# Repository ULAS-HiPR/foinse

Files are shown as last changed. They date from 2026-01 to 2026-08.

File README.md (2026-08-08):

# Foinse

Foinse is the power-source and monitoring node in [Ogma](https://sean-osullivan.com/projects/ogma/), the University of Limerick Aeronautics Society's modular avionics stack for high-powered rocketry.

## Role

- Generates and distributes the shared stack power rails.
- Measures battery and servo current.
- Reports power health over the 500 kbit/s CAN bus.
- Provides the stack's electrical entry point while each node performs its own local regulation.

## Repository

- `hardware/` - KiCad design and manufacturing outputs.
- `firmware/` - embedded firmware, power-path probes, and tests.

## Status

Rev 1 firmware and hardware bring-up continue on [`ogma/flight-hardening`](https://github.com/ULAS-HiPR/foinse/tree/ogma/flight-hardening). Release-candidate firmware builds and software tests pass, but hardware-in-the-loop validation is still underway. Foinse is not yet flight-proven.

## Manufacturing support

Rev 1 PCB fabrication was sponsored through [EasyEDA Education](https://easyeda.com/education) and manufactured by [JLCPCB](https://jlcpcb.com/). The board was designed in KiCad and imported into EasyEDA Pro for the sponsorship and manufacturing workflow.

## More information

See the [Ogma project write-up](https://sean-osullivan.com/projects/ogma/) for the complete stack, bring-up work, and current status.

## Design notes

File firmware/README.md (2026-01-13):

# Foinse

Foinse is in charge of deploying parachutes either through servo’s or ematchs

# Set-Up

```bash
git clone git@github.com:ULAS-HiPR/foinse.git
cd foinse
git submodule update --init --recursive
```

# Libraries used:

## From Braiteoiri:

- Servo
- Ematch
- LED

## From Comheadan:

- CAN
- PWM

## Other:

- FreeRTOS

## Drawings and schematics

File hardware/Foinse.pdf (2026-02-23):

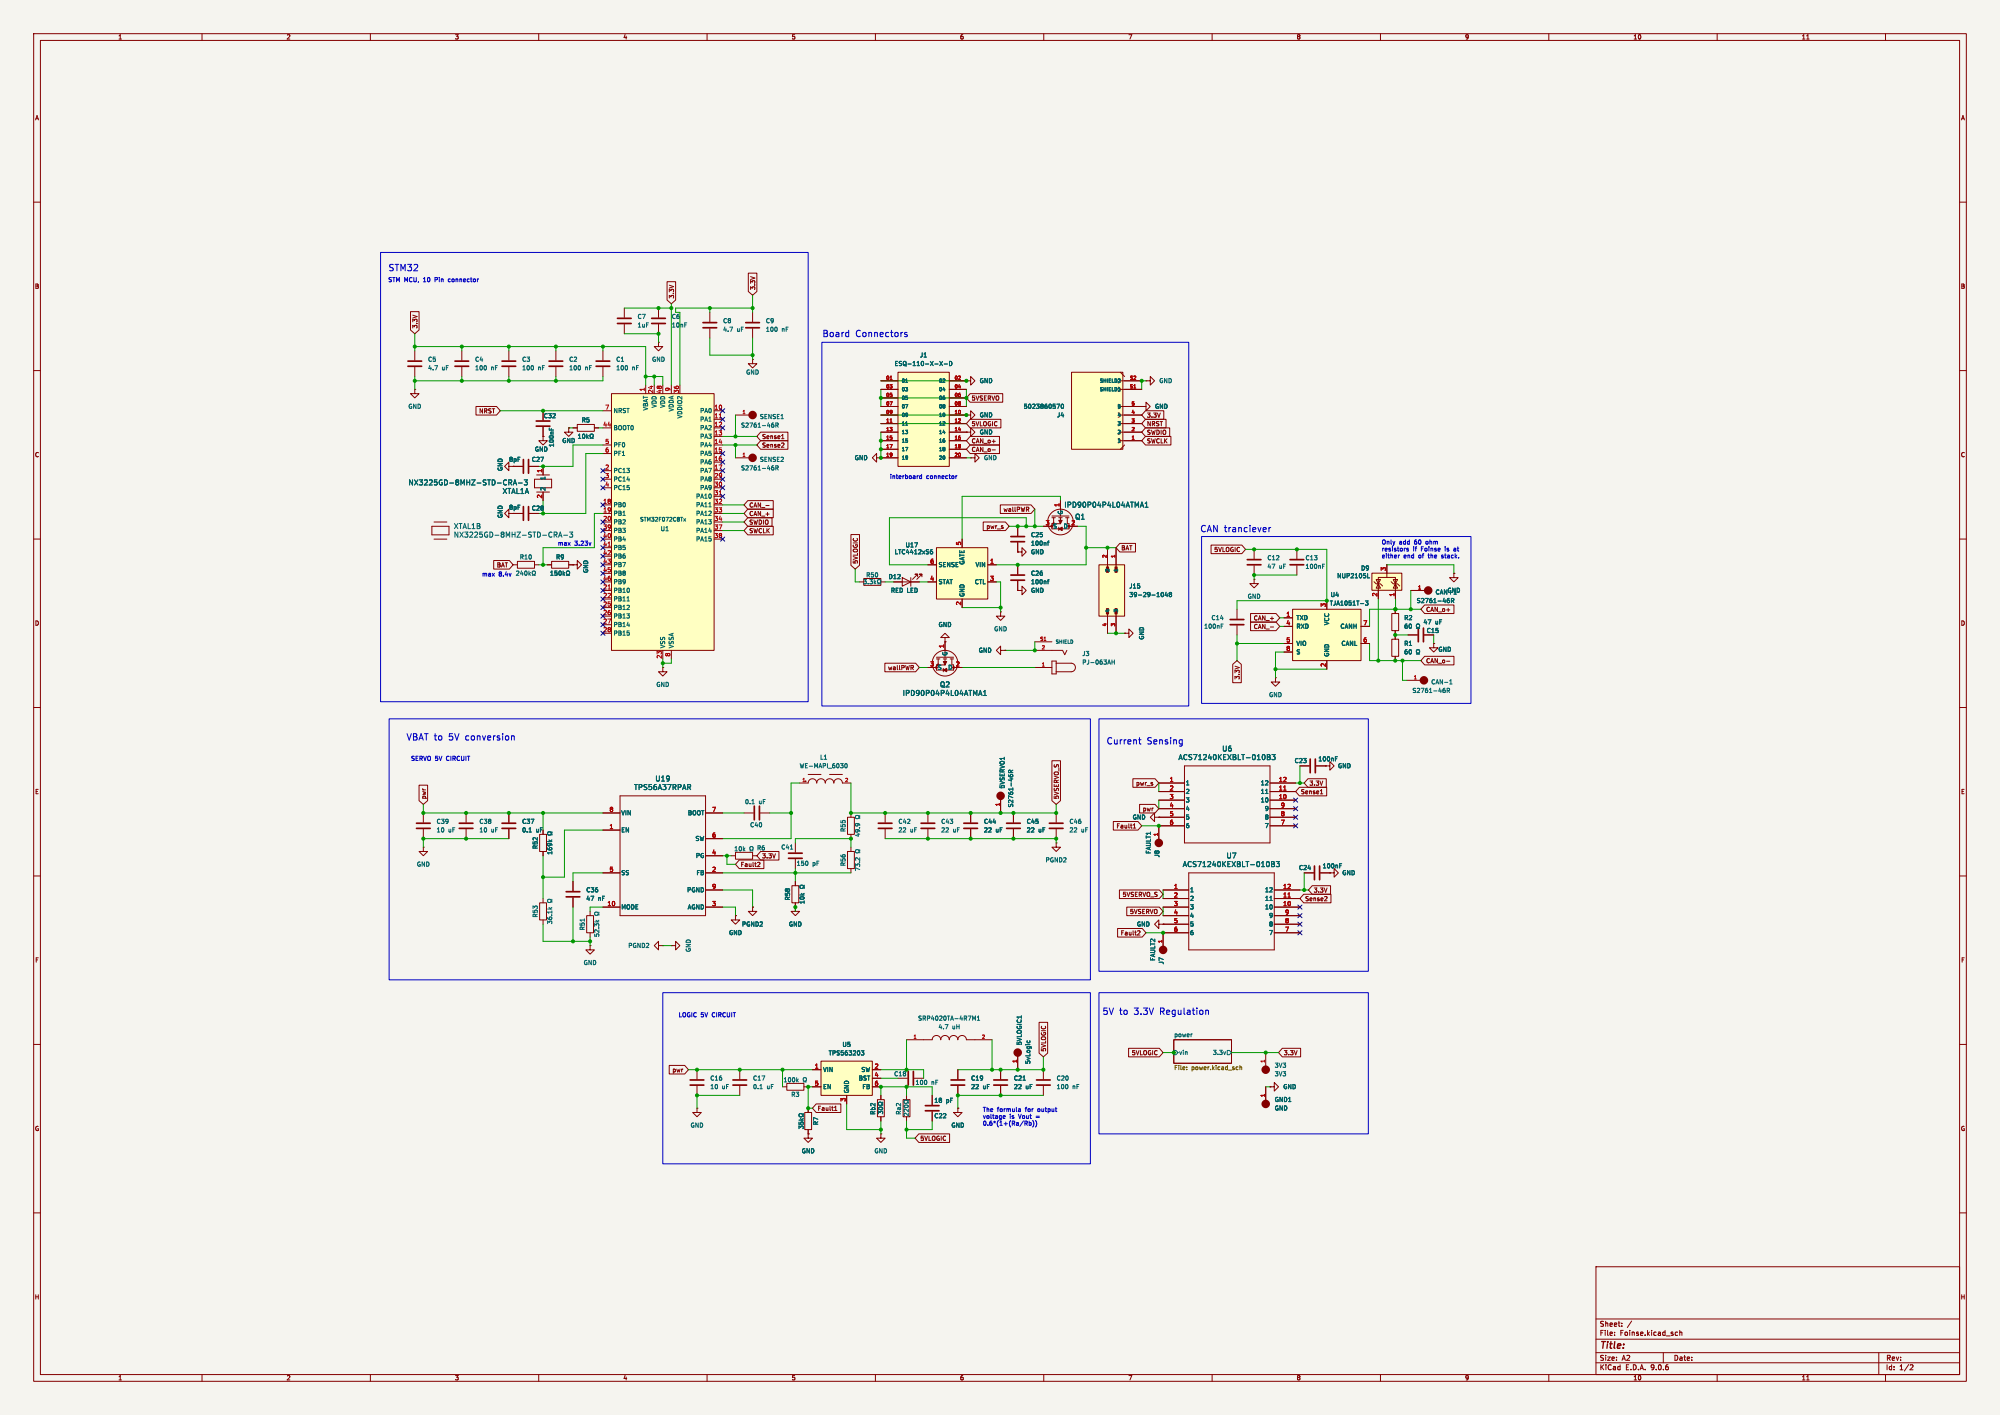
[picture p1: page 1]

1 VDD 24 VDD 48 VSS 23 VDDA

3 SW 2 BST 4 FB 6 U5 TPS563203 R52 169k þÿ©

3 SW 2 BST 4 FB 6 GND

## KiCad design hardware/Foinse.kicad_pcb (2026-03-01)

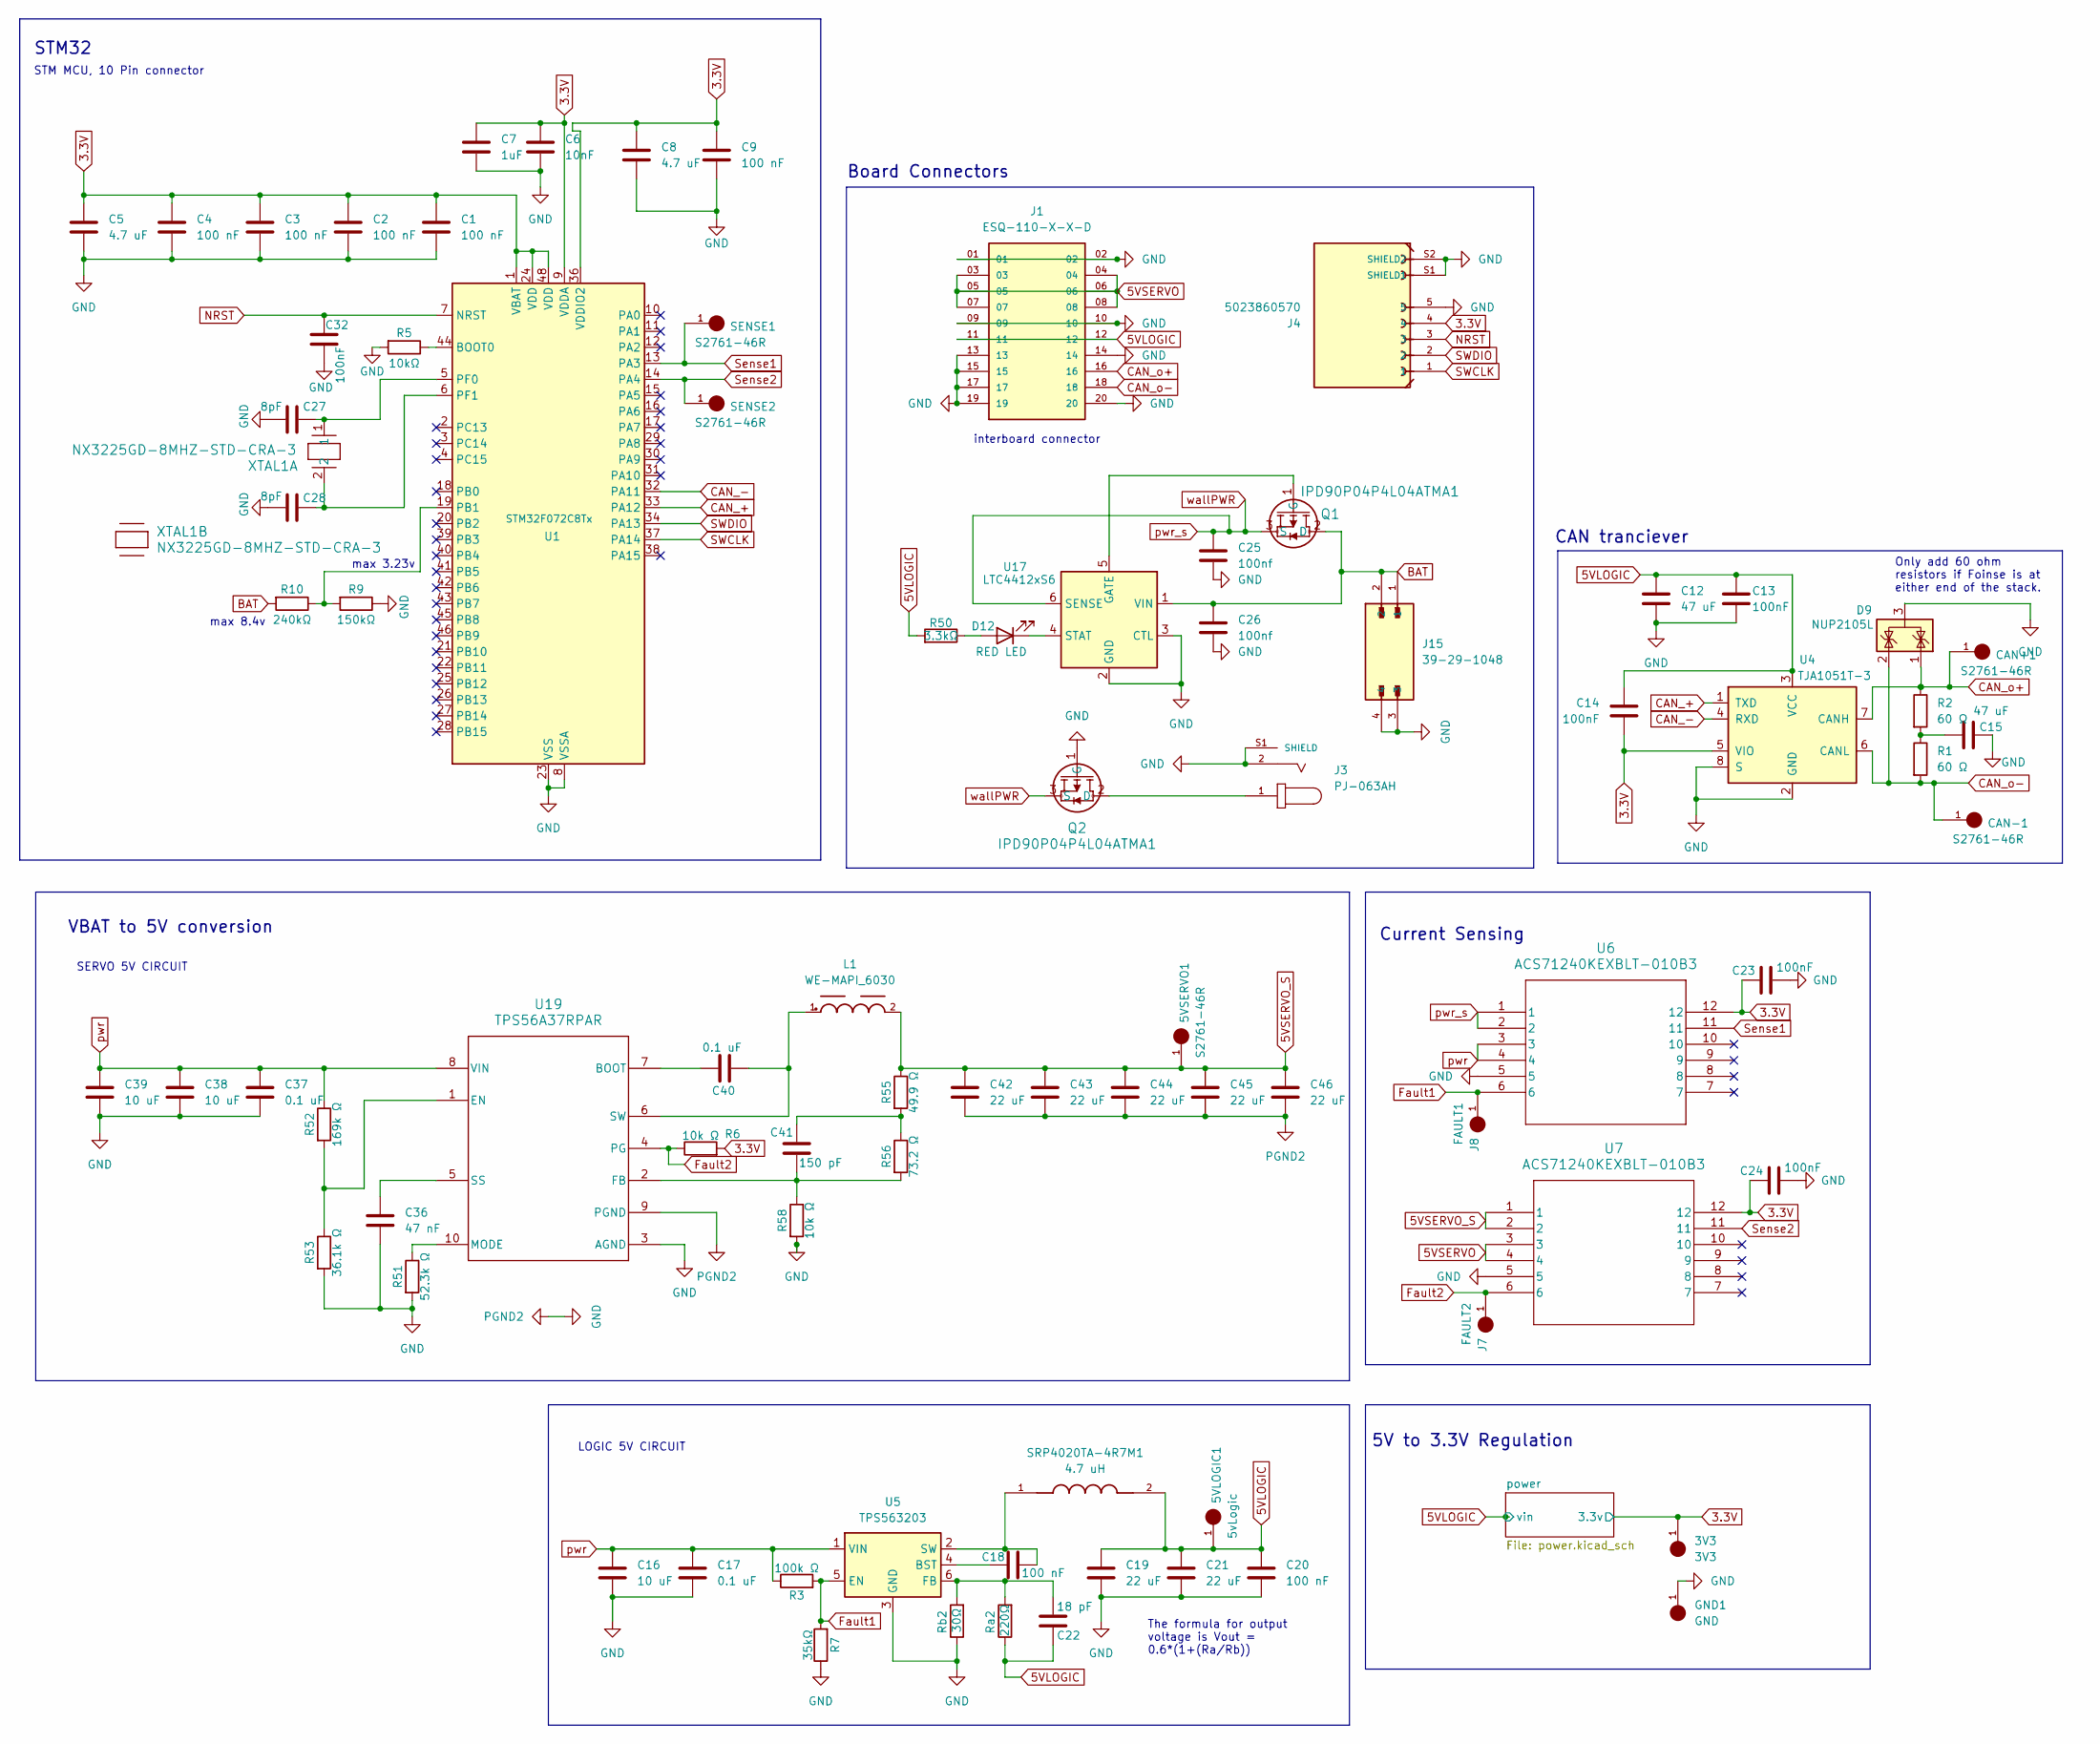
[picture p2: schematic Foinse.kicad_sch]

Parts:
3V3: 3V3; HARWIN_S2761-46R; PARTREV 1
5VLOGIC1: 5vLogic; HARWIN_S2761-46R; PARTREV 1
5VSERVO1: S2761-46R; HARWIN_S2761-46R; PARTREV 1
C1, C2, C3, C4, C9, C18, C20: 100 nF; C_0402_1005Metric
C5, C8: 4.7 uF; C_0402_1005Metric
C6: 10nF; C_0402_1005Metric
C7: 1uF; C_0402_1005Metric
C12, C15: 47 uF; C_0402_1005Metric
C13, C14, C23, C24, C32: 100nF; C_0402_1005Metric
C16, C38, C39: 10 uF; C_0402_1005Metric
C17, C37, C40: 0.1 uF; C_0402_1005Metric
C19, C21, C42, C43, C44, C45, C46: 22 uF; C_0402_1005Metric
C22: 18 pF; C_0402_1005Metric
C25, C26: 100nf; C_0402_1005Metric
C27, C28: 8pF; C_0402_1005Metric
C36: 47 nF; C_0402_1005Metric
C41: 150 pF; C_0402_1005Metric
CAN+1: S2761-46R; HARWIN_S2761-46R; PARTREV 1
CAN-1: S2761-46R; HARWIN_S2761-46R; PARTREV 1
D9: NUP2105L; SOT-23
D12: RED LED; LED_0402_1005Metric
GND1: GND; HARWIN_S2761-46R; PARTREV 1
J1: ESQ-110-X-X-D; SAMTEC_ESQ-110-14-G-D; PARTREV NA
J3: PJ-063AH; CUI_PJ-063AH; PARTREV 1.02
J4: 5023860570; MOLEX_5023860570; PARTREV F
J7: FAULT2; HARWIN_S2761-46R; PARTREV 1
J8: FAULT1; HARWIN_S2761-46R; PARTREV 1
J15: 39-29-1048; MOLEX_39-29-1048
L1: WE-MAPI_6030
Q1, Q2: IPD90P04P4L04ATMA1; PG-TO252-3-313_INF
R1, R2: 60 Ω; R_0402_1005Metric
R3: 100k Ω; R_0402_1005Metric
R5: 10kΩ; R_0402_1005Metric
R6, R58: 10k Ω; R_0402_1005Metric
R7: 35kΩ; R_0402_1005Metric
R9: 150kΩ; R_0402_1005Metric
R10: 240kΩ; R_0402_1005Metric
R50: 3.3kΩ; R_0402_1005Metric
R51: 52.3k Ω; R_0402_1005Metric
R52: 169k Ω; R_0402_1005Metric
R53: 36.1k Ω; R_0402_1005Metric
R55: 49.9 Ω; R_0402_1005Metric
R56: 73.2 Ω; R_0402_1005Metric
Ra2: 220Ω; R_0402_1005Metric
Rb2: 30Ω; R_0402_1005Metric
SENSE1, SENSE2: S2761-46R; HARWIN_S2761-46R; PARTREV 1
SRP4020TA-4R7M1: 4.7 uH; IND_SRP4020TA-4R7M
U1: STM32F072C8Tx; LQFP-48_7x7mm_P0.5mm
U4: TJA1051T-3; SOIC-8_3.9x4.9mm_P1.27mm
U5: TPS563203; SOT-563
U6, U7: ACS71240KEXBLT-010B3; QFN12_ACS711KEXLT-31AB-T_ALM
U17: LTC4412xS6; TSOT-23-6
U19: TPS56A37RPAR; RPA0010A-MFG
XTAL1: NX3225GD-8MHZ-STD-CRA-3; XTAL_NX3225GD-8MHZ-STD-CRA-3_NDK

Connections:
3.3V: 3V3.1, C1.1, C2.1, C3.1, C4.1, C5.1, C6.1, C7.1, C8.1, C9.1, C14.1, C23.2, C24.2, J4.4, R6.2, U1.1 (VBAT), U1.9 (VDDA), U1.24 (VDD), U1.36 (VDDIO2), U1.48 (VDD), U4.5 (VIO), U6.12, U7.12; also elsewhere on the board
5VLOGIC: 5VLOGIC1.1, C12.1, C13.1, C14.2, C19.1, C20.1, C21.1, C22.2, J1.11, J1.12, R50.2, Ra2.1, SRP4020TA-4R7M1.2, U4.3 (VCC); also elsewhere on the board
5VSERVO: J1.03, J1.04, J1.05, J1.06, J1.07, J1.08, U7.3, U7.4
5VSERVO_S: 5VSERVO1.1, C42.1, C43.1, C44.1, C45.1, C46.1, L1.2, R55.1, U7.1, U7.2; also elsewhere on the board
BAT: C26.1, J15.1, J15.2, Q1.2 (D), R10.2, U17.1 (VIN)
CAN_+: U1.33 (PA12), U4.1 (TXD)
CAN_-: U1.32 (PA11), U4.4 (RXD)
CAN_o+: CAN+1.1, D9.1 (K), J1.16, R2.1, U4.7 (CANH); also elsewhere on the board
CAN_o-: CAN-1.1, D9.2 (K), J1.18, R1.2, U4.6 (CANL); also elsewhere on the board
Fault1: J8.1, R3.2, R7.2, U5.5 (EN), U6.6; also elsewhere on the board
Fault2: J7.1, R6.1, U7.6, U19.4 (PG); also elsewhere on the board
GND: C1.2, C2.2, C3.2, C4.2, C5.2, C6.2, C7.2, C8.2, C9.2, C12.2, C13.2, C15.2, C16.2, C17.2, C19.2, C20.2, C21.2, C23.1, C24.1, C25.2, C26.2, C27.1, C28.2, C32.2, C36.2, C37.2, C38.2, C39.2, C42.2, C43.2, C44.2, C45.2, C46.2, D9.3 (A), GND1.1, J1.01, J1.02, J1.09, J1.10, J1.13, J1.14, J1.15, J1.17, J1.19, J1.20, J3.2, J3.S1 (SHIELD), J3.S2 (SHIELD), J4.5, J4.S1 (SHIELD1), J4.S2 (SHIELD2), J15.3, J15.4, Q2.1 (G), R5.2, R7.1, R9.1, R51.2, R53.2, R58.2, Rb2.1, U1.8 (VSSA), U1.23 (VSS), U1.35 (VSS), U1.47 (VSS), U4.2 (GND), U4.8 (S), U5.3 (GND), U6.5, U7.5, U17.2 (GND), U17.3 (CTL), U19.3 (AGND), U19.9 (PGND); also elsewhere on the board
NRST: C32.1, J4.3, U1.7 (NRST)
unnamed: C15.1, R1.1, R2.2
unnamed: C41.1, R55.2, R56.1
unnamed: D12.2 (A), R50.1
unnamed: D12.1 (K), U17.4 (STAT)
unnamed: Q1.1 (G), U17.5 (GATE)
unnamed: J3.1, Q2.2 (D)
unnamed: R5.1, U1.44 (BOOT0)
unnamed: R9.2, R10.1, U1.19 (PB1)
unnamed: C27.2, U1.5 (PF0), XTAL1.1
unnamed: C28.1, U1.6 (PF1), XTAL1.2
unnamed: C18.2, U5.4 (BST)
unnamed: C22.1, Ra2.2, Rb2.2, U5.6 (FB)
unnamed: C18.1, SRP4020TA-4R7M1.1, U5.2 (SW)
unnamed: C40.1, U19.7 (BOOT)
unnamed: R52.2, R53.1, U19.1 (EN)
unnamed: C41.2, R56.2, R58.1, U19.2 (FB)
unnamed: R51.1, U19.10 (MODE)
unnamed: C36.1, U19.5 (SS)
unnamed: C40.2, L1.1, U19.6 (SW)
SWCLK: J4.1, U1.37 (PA14)
SWDIO: J4.2, U1.34 (PA13)
Sense1: SENSE1.1, U1.13 (PA3), U6.11; also elsewhere on the board
Sense2: SENSE2.1, U1.14 (PA4), U7.11; also elsewhere on the board
pwr: C16.1, C17.1, C37.1, C38.1, C39.1, R3.1, R52.1, U5.1 (VIN), U6.3, U6.4, U19.8 (VIN)
pwr_s: C25.1, Q1.3 (S), Q2.3 (S), U6.1, U6.2, U17.6 (SENSE)

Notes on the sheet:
max 3.23v
Board Connectors
5V to 3.3V Regulation
Current Sensing
interboard connector
STM MCU, 10 Pin connector
STM32
max 8.4v
VBAT to 5V conversion
CAN tranciever
LOGIC 5V CIRCUIT
SERVO 5V CIRCUIT
Only add 60 ohm resistors if Foinse is at either end of the stack.
The formula for output voltage is Vout = 0.6*(1+(Ra/Rb))

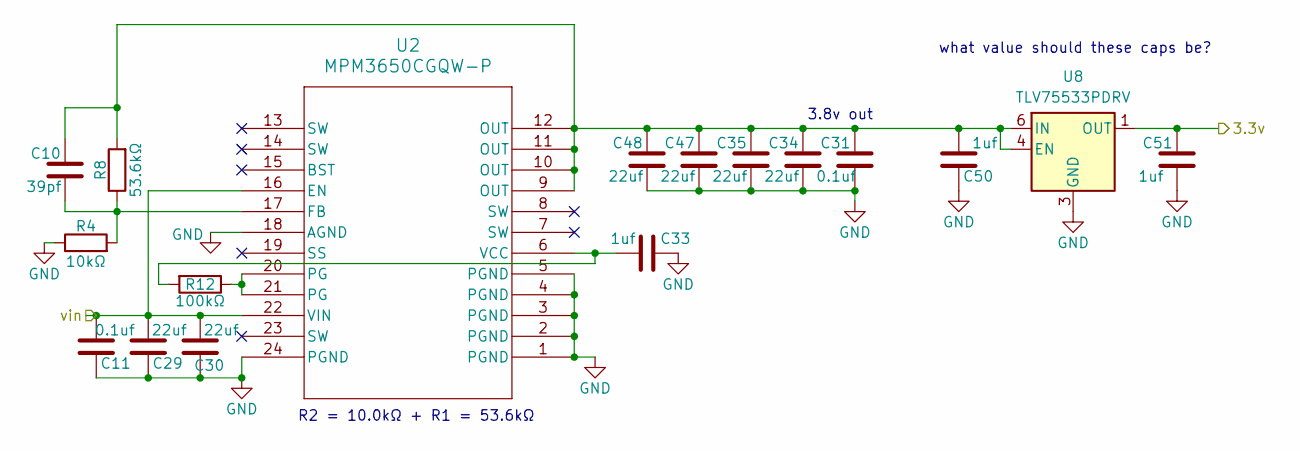
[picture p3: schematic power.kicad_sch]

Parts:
C10: 39pf; C_0402_1005Metric
C11, C31: 0.1uf; C_0402_1005Metric
C29, C30, C34, C35, C47, C48: 22uf; C_0402_1005Metric
C33, C50, C51: 1uf; C_0402_1005Metric
R4: 10kΩ; R_0402_1005Metric
R8: 53.6kΩ; R_0402_1005Metric
R12: 100kΩ; R_0402_1005Metric
U2: MPM3650CGQW-P; QFN-24_MPM3650_MNP
U8: TLV75533PDRV; WSON-6-1EP_2x2mm_P0.65mm_EP1x1.6mm

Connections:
3.3V: C51.1, U8.1 (OUT); also elsewhere on the board
5VLOGIC: C11.2, C29.2, C30.2, U2.16 (EN), U2.22 (VIN); also elsewhere on the board
GND: C11.1, C29.1, C30.1, C31.2, C33.1, C34.2, C35.2, C47.2, C48.2, C50.1, C51.2, R4.1, U2.1 (PGND), U2.2 (PGND), U2.3 (PGND), U2.4 (PGND), U2.5 (PGND), U2.18 (AGND), U2.24 (PGND), U8.3 (GND), U8.7 (GND); also elsewhere on the board
unnamed: R12.1, U2.20 (PG), U2.21 (PG)
unnamed: C10.2, R4.2, R8.1, U2.17 (FB)
unnamed: C33.2, R12.2, U2.6 (VCC)
unnamed: C10.1, C31.1, C34.1, C35.1, C47.1, C48.1, C50.2, R8.2, U2.9 (OUT), U2.10 (OUT), U2.11 (OUT), U2.12 (OUT), U8.4 (EN), U8.6 (IN)

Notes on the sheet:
R2 = 10.0kΩ + R1 = 53.6kΩ
3.8v out
what value should these caps be?

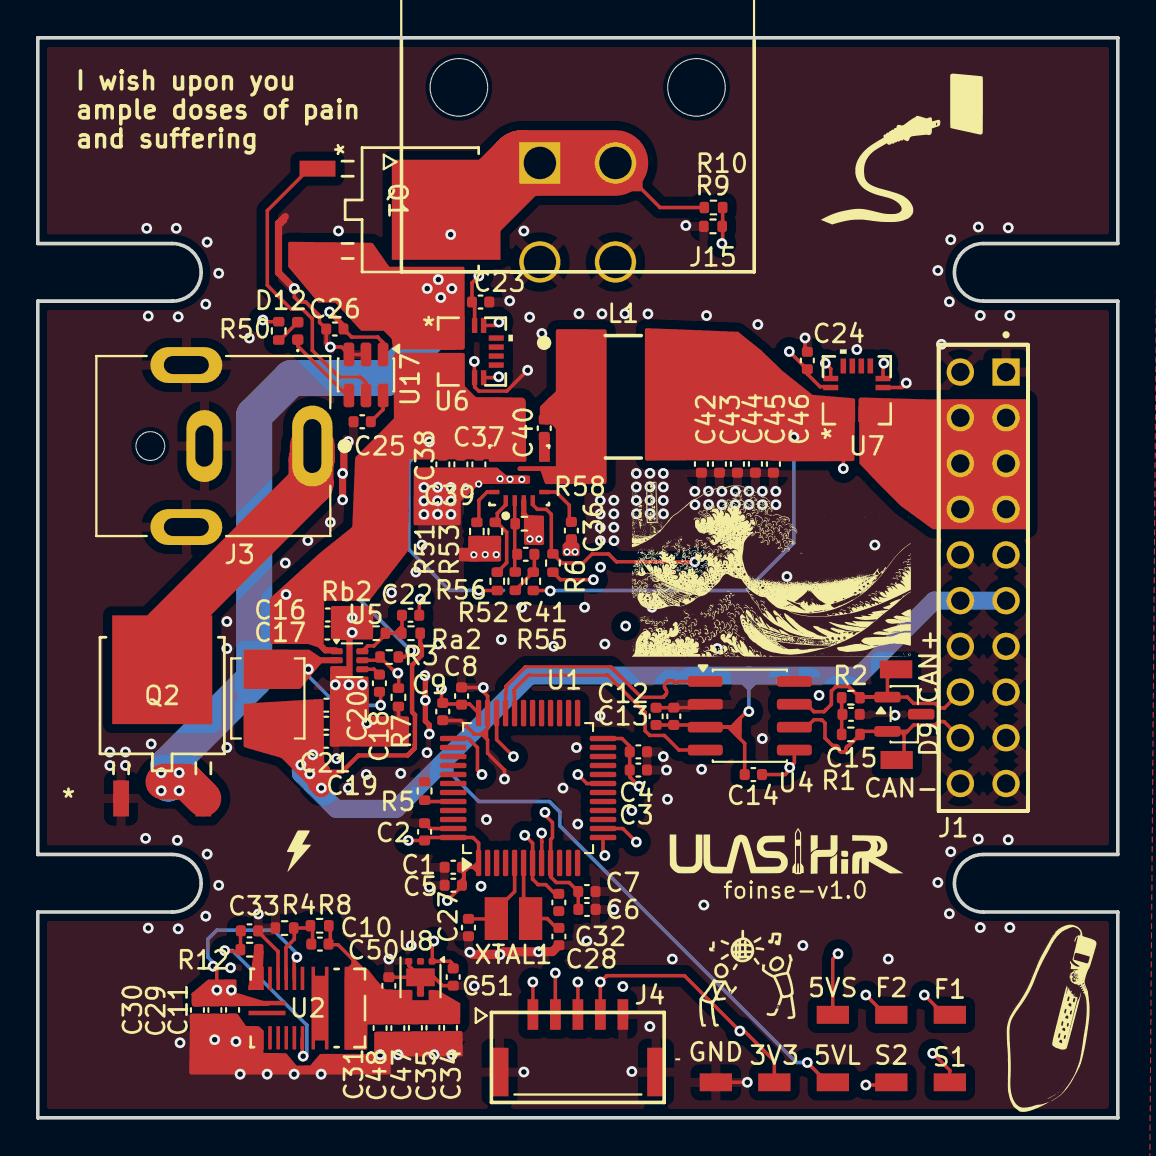
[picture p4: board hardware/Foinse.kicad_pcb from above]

Board: 6 copper layers, 60.0 x 60.0 mm, 100 parts (0 on the bottom side), 42 nets.

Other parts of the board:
5VL: 5vLogic; HARWIN_S2761-46R
5VS: S2761-46R; HARWIN_S2761-46R
CAN+: S2761-46R; HARWIN_S2761-46R
CAN-: S2761-46R; HARWIN_S2761-46R
F1: FAULT1; HARWIN_S2761-46R
F2: FAULT2; HARWIN_S2761-46R
GND: GND; HARWIN_S2761-46R
S1, S2: S2761-46R; HARWIN_S2761-46R

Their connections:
5VLOGIC: 5VL.1; also elsewhere on the board
5VSERVO_S: 5VS.1; also elsewhere on the board
CAN_o+: CAN+.1; also elsewhere on the board
CAN_o-: CAN-.1; also elsewhere on the board
Fault1: F1.1; also elsewhere on the board
Fault2: F2.1; also elsewhere on the board
GND: GND.1; also elsewhere on the board
Sense1: S1.1; also elsewhere on the board
Sense2: S2.1; also elsewhere on the board

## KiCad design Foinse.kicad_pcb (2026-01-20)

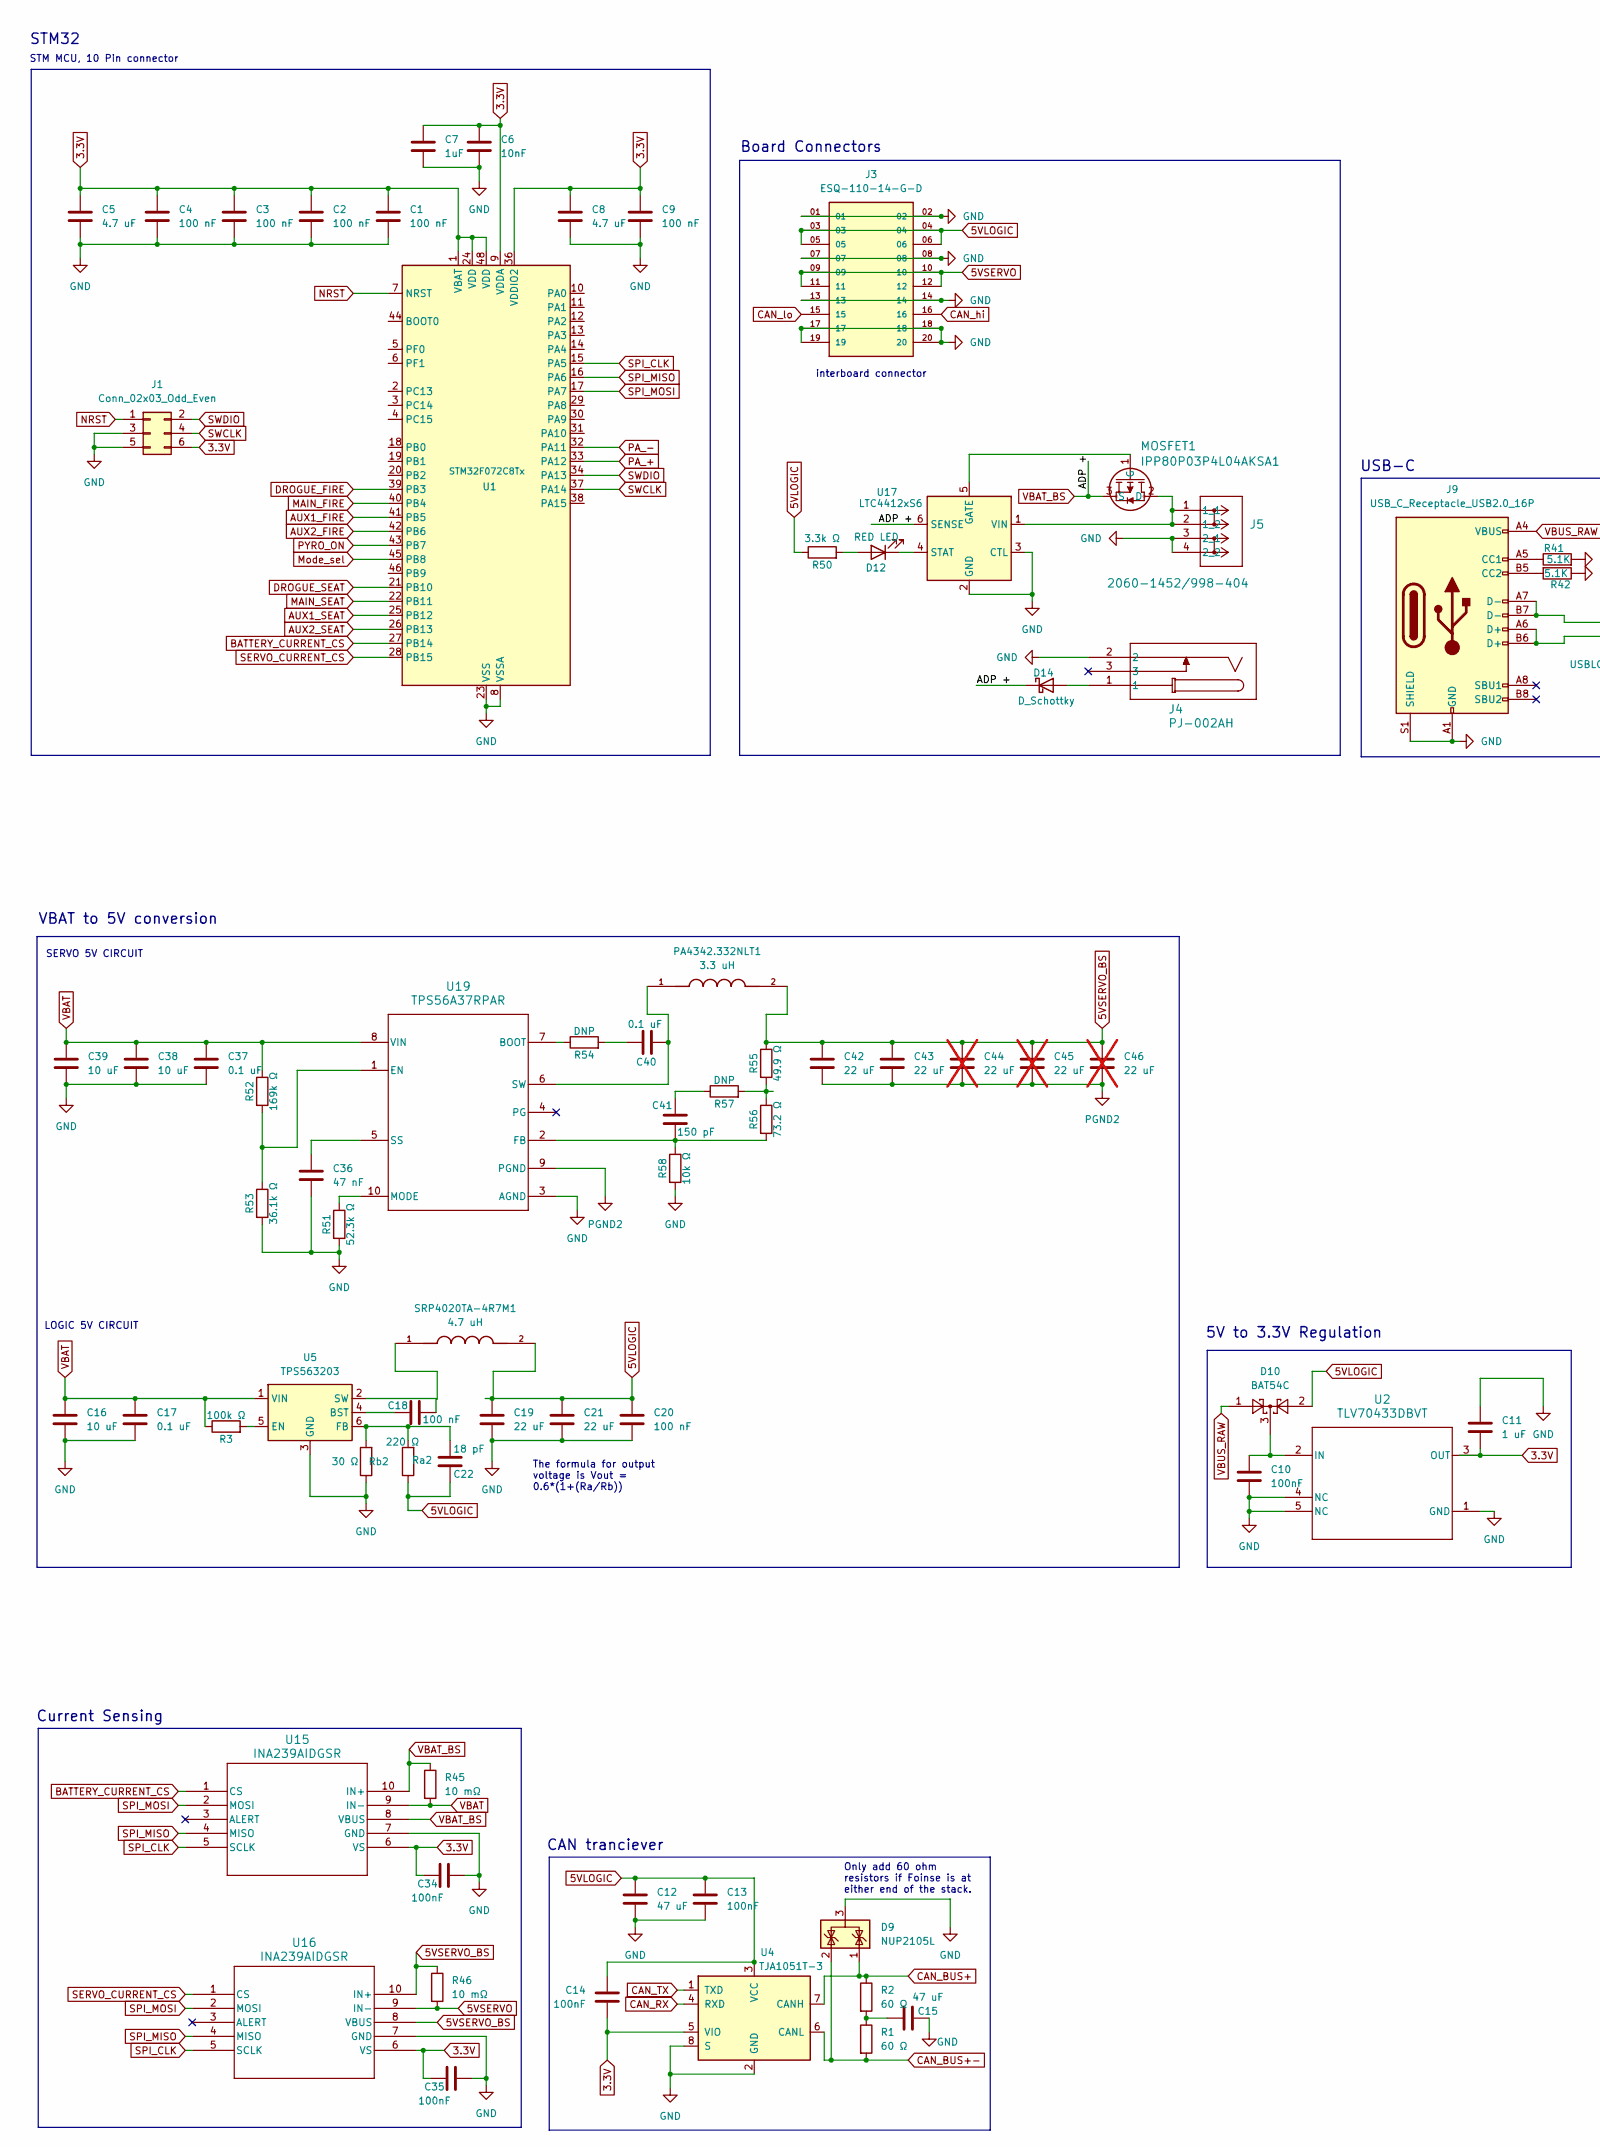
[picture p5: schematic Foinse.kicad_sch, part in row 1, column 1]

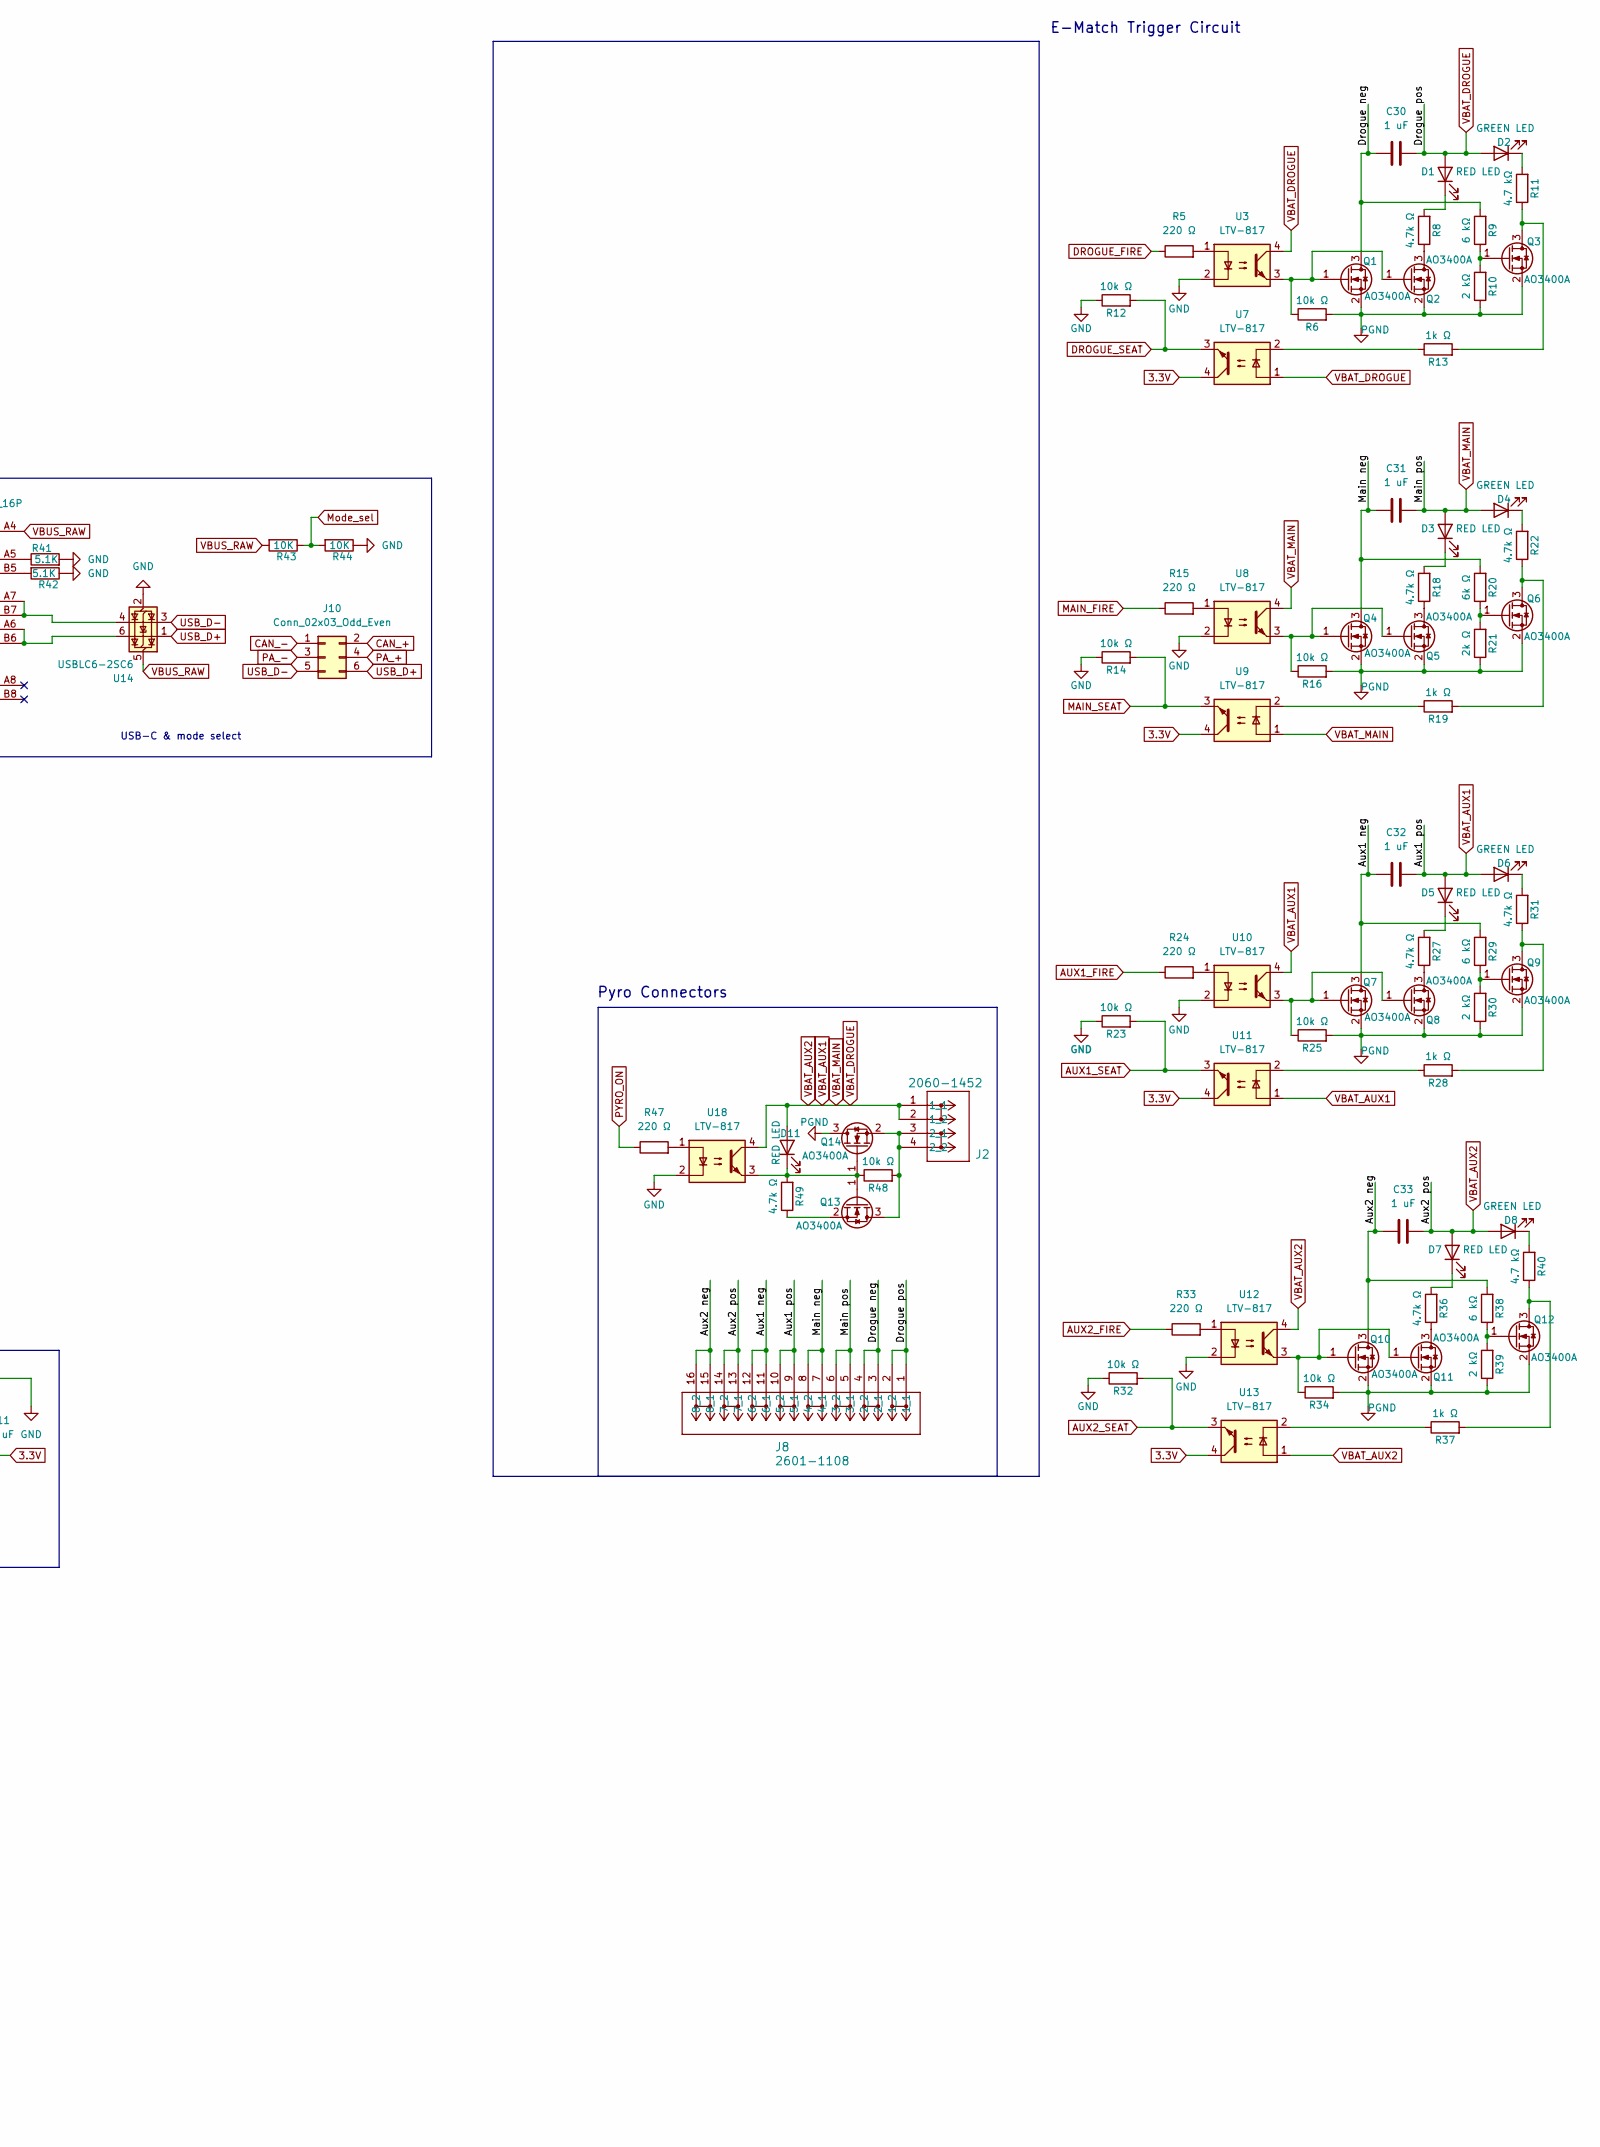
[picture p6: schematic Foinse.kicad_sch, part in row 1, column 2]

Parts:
C1, C2, C3, C4, C9, C18, C20: 100 nF; C_0402_1005Metric
C5, C8: 4.7 uF; C_0402_1005Metric
C6: 10nF; C_0402_1005Metric
C7: 1uF; C_0402_1005Metric
C10, C13, C14, C34, C35: 100nF; C_0402_1005Metric
C11, C30, C31, C32, C33: 1 uF; C_0402_1005Metric
C12, C15: 47 uF; C_0402_1005Metric
C16, C38, C39: 10 uF; C_0402_1005Metric
C17, C37, C40: 0.1 uF; C_0402_1005Metric
C19, C21, C42, C43: 22 uF; C_0402_1005Metric
C22: 18 pF; C_0402_1005Metric
C36: 47 nF; C_0402_1005Metric
C41: 150 pF; C_0402_1005Metric
C44, C45, C46: 22 uF; C_0402_1005Metric; not fitted
D1, D3, D5, D7, D11, D12: RED LED; LED_0402_1005Metric
D2, D4, D6, D8: GREEN LED; LED_0402_1005Metric
D9: NUP2105L; SOT-23
D10: BAT54C; SOT-23
D14: D_Schottky; TO-220-3_Vertical
J1, J10: Conn_02x03_Odd_Even; PinHeader_2x03_P1.00mm_Vertical
J2: 2060-1452; WAG
J3: ESQ-110-14-G-D; SAMTEC_ESQ-110-14-G-D; PARTREV NA
J4: PJ-002AH; PJ-002AH_CUD
J5: 2060-1452/998-404; WAG
J8: 2601-1108; CONN8_2601-1108_WAG
J9: USB_C_Receptacle_USB2.0_16P; USB_C_Receptacle_G-Switch_GT-USB-7010ASV
MOSFET1: IPP80P03P4L04AKSA1
PA4342.332NLT1: 3.3 uH; IND_PA4342.332NLT; PARTREV P769.L (06/20)
Q1, Q2, Q3, Q4, Q5, Q6, Q7, Q8, Q9, Q10, Q11, Q12, Q13, Q14: AO3400A; SOT-23
R1, R2: 60 Ω; R_0402_1005Metric
R3: 100k Ω; R_0402_1005Metric
R5, R15, R24, R33, R47: 220 Ω; R_0402_1005Metric
R6, R12, R14, R16, R23, R25, R32, R34, R48, R58: 10k Ω; R_0402_1005Metric
R8, R18, R22, R27, R31, R36, R49: 4.7k Ω; R_0402_1005Metric
R9, R29, R38: 6 kΩ; R_0402_1005Metric
R10, R30, R39: 2 kΩ; R_0402_1005Metric
R11, R40: 4.7 kΩ; R_0402_1005Metric
R13, R19, R28, R37: 1k Ω; R_0402_1005Metric
R20: 6k Ω; R_0402_1005Metric
R21: 2k Ω; R_0402_1005Metric
R41, R42: 5.1K; R_0402_1005Metric
R43, R44: 10K; R_0402_1005Metric
R45, R46: 10 mΩ; R_0402_1005Metric
R50: 3.3k Ω; R_0402_1005Metric
R51: 52.3k Ω; R_0402_1005Metric
R52: 169k Ω; R_0402_1005Metric
R53: 36.1k Ω; R_0402_1005Metric
R54, R57: DNP; R_0402_1005Metric
R55: 49.9 Ω; R_0402_1005Metric
R56: 73.2 Ω; R_0402_1005Metric
Ra2: 220 Ω; R_0402_1005Metric
Rb2: 30 Ω; R_0402_1005Metric
SRP4020TA-4R7M1: 4.7 uH; IND_SRP4020TA-4R7M
U1: STM32F072C8Tx; LQFP-48_7x7mm_P0.5mm
U2: TLV70433DBVT; DBV0005A_N
U3, U7, U8, U9, U10, U11, U12, U13, U18: LTV-817; SO4_TOS
U4: TJA1051T-3; SOIC-8_3.9x4.9mm_P1.27mm
U5: TPS563203; SOT-563
U14: USBLC6-2SC6; SOT-23-6
U15, U16: INA239AIDGSR; VSSOP_9AIDGST_TEX
U17: LTC4412xS6; TSOT-23-6
U19: TPS56A37RPAR; RPA0010A-MFG

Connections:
3.3V: C1.1, C2.1, C3.1, C4.1, C5.1, C6.1, C7.1, C8.1, C9.1, C11.2, C14.1, C34.1, C35.1, J1.6, U1.1 (VBAT), U1.9 (VDDA), U1.24 (VDD), U1.36 (VDDIO2), U1.48 (VDD), U2.3 (OUT), U4.5 (VIO), U7.4, U9.4, U11.4, U13.4, U15.6 (VS), U16.6 (VS)
5VLOGIC: C12.1, C13.1, C14.2, C19.1, C20.1, C21.1, C22.2, D10.2, J3.03, J3.04, J3.05, J3.06, R50.1, Ra2.1, U4.3 (VCC)
5VSERVO: J3.09, J3.10, J3.11, J3.12, R46.2, U16.9 (IN-)
5VSERVO_BS: C42.1, C43.1, C44.1, C45.1, C46.1, PA4342.332NLT1.2, R46.1, R55.1, U16.8 (VBUS), U16.10 (IN+)
/Aux1 neg: C32.2, J8.11 (6_1), J8.12 (6_2), Q7.3 (D), R29.2
/Aux2 neg: C33.2, J8.15 (8_1), J8.16 (8_2), Q10.3 (D), R38.2
/Drogue neg: C30.2, J8.3 (2_1), J8.4 (2_2), Q1.3 (D), R9.2
/Main neg: C31.2, J8.7 (4_1), J8.8 (4_2), Q4.3 (D), R20.2
AUX1_FIRE: R24.1, U1.41 (PB5)
AUX1_SEAT: R23.2, U1.25 (PB12), U11.3
AUX2_FIRE: R33.1, U1.42 (PB6)
AUX2_SEAT: R32.2, U1.26 (PB13), U13.3
BATTERY_CURRENT_CS: U1.27 (PB14), U15.1 (CS)
CAN_+: J10.2
CAN_-: J10.1
CAN_BUS+: D9.1 (K), R2.1, U4.7 (CANH)
CAN_BUS+-: D9.2 (K), R1.2, U4.6 (CANL)
CAN_RX: U4.4 (RXD)
CAN_TX: U4.1 (TXD)
CAN_hi: J3.16
CAN_lo: J3.15
DROGUE_FIRE: R5.1, U1.39 (PB3)
DROGUE_SEAT: R12.2, U1.21 (PB10), U7.3
GND: C1.2, C2.2, C3.2, C4.2, C5.2, C6.2, C7.2, C8.2, C9.2, C10.2, C11.1, C12.2, C13.2, C15.2, C16.2, C17.2, C19.2, C20.2, C21.2, C34.2, C35.2, C36.2, C37.2, C38.2, C39.2, D9.3 (A), J1.3, J1.5, J3.01, J3.02, J3.07, J3.08, J3.13, J3.14, J3.17, J3.18, J3.19, J3.20, J4.2, J5.3 (2_1), J5.4 (2_2), J9.A1 (GND), J9.A12 (GND), J9.B1 (GND), J9.B12 (GND), J9.S1 (SHIELD), R12.1, R14.1, R23.1, R32.1, R41.2, R42.1, R44.1, R51.2, R53.2, R58.2, Rb2.1, U1.8 (VSSA), U1.23 (VSS), U1.35 (VSS), U1.47 (VSS), U2.1 (GND), U2.4 (NC), U2.5 (NC), U3.2, U4.2 (GND), U4.8 (S), U5.3 (GND), U8.2, U10.2, U12.2, U14.2 (GND), U15.7 (GND), U16.7 (GND), U17.2 (GND), U17.3 (CTL), U18.2, U19.3 (AGND)
MAIN_FIRE: R15.1, U1.40 (PB4)
MAIN_SEAT: R14.2, U1.22 (PB11), U9.3
Mode_sel: R43.1, R44.2, U1.45 (PB8)
NRST: J1.1, U1.7 (NRST)
unnamed: C15.1, R1.1, R2.2
unnamed: C40.1, R54.2
unnamed: C41.1, R57.1
unnamed: D1.1 (K), R8.2
unnamed: D2.1 (K), R11.2
unnamed: D3.1 (K), R18.2
unnamed: D4.1 (K), R22.2
unnamed: D5.1 (K), R27.2
unnamed: D6.1 (K), R31.2
unnamed: D7.1 (K), R36.2
unnamed: D8.1 (K), R40.2
unnamed: D11.1 (K), Q13.1 (G), Q14.1 (G), R48.1, R49.2, U18.3
unnamed: D12.2 (A), R50.2
unnamed: D12.1 (K), U17.4 (STAT)
unnamed: D14.2 (A), J4.1
unnamed: J2.3 (2_1), J2.4 (2_2), Q13.3 (D), Q14.2 (S), R48.2
unnamed: J5.1 (1_1), J5.2 (1_2), MOSFET1.2 (D), U17.1 (VIN)
unnamed: J9.A5 (CC1), R41.1
unnamed: J9.B5 (CC2), R42.2
unnamed: J9.A6 (D+), J9.B6 (D+), U14.6 (I/O1)
unnamed: J9.A7 (D-), J9.B7 (D-), U14.4 (I/O2)
unnamed: MOSFET1.1 (G), U17.5 (GATE)
unnamed: Q1.1 (G), Q2.1 (G), R6.1, U3.3
unnamed: Q2.3 (D), R8.1
unnamed: Q3.3 (D), R11.1, R13.2
unnamed: Q3.1 (G), R9.1, R10.2
unnamed: Q4.1 (G), Q5.1 (G), R16.1, U8.3
unnamed: Q5.3 (D), R18.1
unnamed: Q6.3 (D), R19.2, R22.1
unnamed: Q6.1 (G), R20.1, R21.2
unnamed: Q7.1 (G), Q8.1 (G), R25.1, U10.3
unnamed: Q8.3 (D), R27.1
unnamed: Q9.3 (D), R28.2, R31.1
unnamed: Q9.1 (G), R29.1, R30.2
unnamed: Q10.1 (G), Q11.1 (G), R34.1, U12.3
unnamed: Q11.3 (D), R36.1
unnamed: Q12.3 (D), R37.2, R40.1
unnamed: Q12.1 (G), R38.1, R39.2
unnamed: Q13.2 (S), R49.1
unnamed: R5.2, U3.1
unnamed: R13.1, U7.2
unnamed: R15.2, U8.1
unnamed: R19.1, U9.2
unnamed: R24.2, U10.1
unnamed: R28.1, U11.2
unnamed: R33.2, U12.1
unnamed: R37.1, U13.2
unnamed: R47.2, U18.1
unnamed: R55.2, R56.1, R57.2
unnamed: C10.1, D10.3, U2.2 (IN)
unnamed: C18.2, U5.4 (BST)
unnamed: R3.2, U5.5 (EN)
unnamed: C22.1, Ra2.2, Rb2.2, U5.6 (FB)
unnamed: C18.1, U5.2 (SW)
unnamed: R54.1, U19.7 (BOOT)
unnamed: R52.2, R53.1, U19.1 (EN)
unnamed: C41.2, R56.2, R58.1, U19.2 (FB)
unnamed: R51.1, U19.10 (MODE)
unnamed: C36.1, U19.5 (SS)
unnamed: C40.2, PA4342.332NLT1.1, U19.6 (SW)
PA_+: J10.4, U1.33 (PA12)
PA_-: J10.3, U1.32 (PA11)
PGND: Q1.2 (S), Q2.2 (S), Q3.2 (S), Q4.2 (S), Q5.2 (S), Q6.2 (S), Q7.2 (S), Q8.2 (S), Q9.2 (S), Q10.2 (S), Q11.2 (S), Q12.2 (S), Q14.3 (D), R6.2, R10.1, R16.2, R21.1, R25.2, R30.1, R34.2, R39.1
PGND2: C42.2, C43.2, C44.2, C45.2, C46.2, U19.9 (PGND)
PYRO_ON: R47.1, U1.43 (PB7)
SERVO_CURRENT_CS: U1.28 (PB15), U16.1 (CS)
SPI_CLK: U1.15 (PA5), U15.5 (SCLK), U16.5 (SCLK)
SPI_MISO: U1.16 (PA6), U15.4 (MISO), U16.4 (MISO)
SPI_MOSI: U1.17 (PA7), U15.2 (MOSI), U16.2 (MOSI)
SWCLK: J1.4, U1.37 (PA14)
SWDIO: J1.2, U1.34 (PA13)
USB_D+: J10.6, U14.1 (I/O1)
USB_D-: J10.5, U14.3 (I/O2)
VBAT: C16.1, C17.1, C37.1, C38.1, C39.1, R3.1, R45.2, R52.1, U5.1 (VIN), U15.9 (IN-), U19.8 (VIN)
VBAT_AUX1: C30.1, C31.1, C32.1, C33.1, D1.2 (A), D2.2 (A), D3.2 (A), D4.2 (A), D5.2 (A), D6.2 (A), D7.2 (A), D8.2 (A), D11.2 (A), J2.1 (1_1), J2.2 (1_2), J8.1 (1_1), J8.2 (1_2), J8.5 (3_1), J8.6 (3_2), J8.9 (5_1), J8.10 (5_2), J8.13 (7_1), J8.14 (7_2), U3.4, U7.1, U8.4, U9.1, U10.4, U11.1, U12.4, U13.1, U18.4
VBAT_BS: D14.1 (K), MOSFET1.3 (S), R45.1, U15.8 (VBUS), U15.10 (IN+), U17.6 (SENSE)
VBUS_RAW: D10.1, J9.A4 (VBUS), J9.A9 (VBUS), J9.B4 (VBUS), J9.B9 (VBUS), R43.2, U14.5 (VBUS)

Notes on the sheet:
Board Connectors
Pyro Connectors
E-Match Trigger Circuit
interboard connector
5V to 3.3V Regulation
Current Sensing
STM MCU, 10 Pin connector
STM32
USB-C & mode select
USB-C
VBAT to 5V conversion
CAN tranciever
LOGIC 5V CIRCUIT
SERVO 5V CIRCUIT
Only add 60 ohm resistors if Foinse is at either end of the stack.
The formula for output voltage is Vout = 0.6*(1+(Ra/Rb))

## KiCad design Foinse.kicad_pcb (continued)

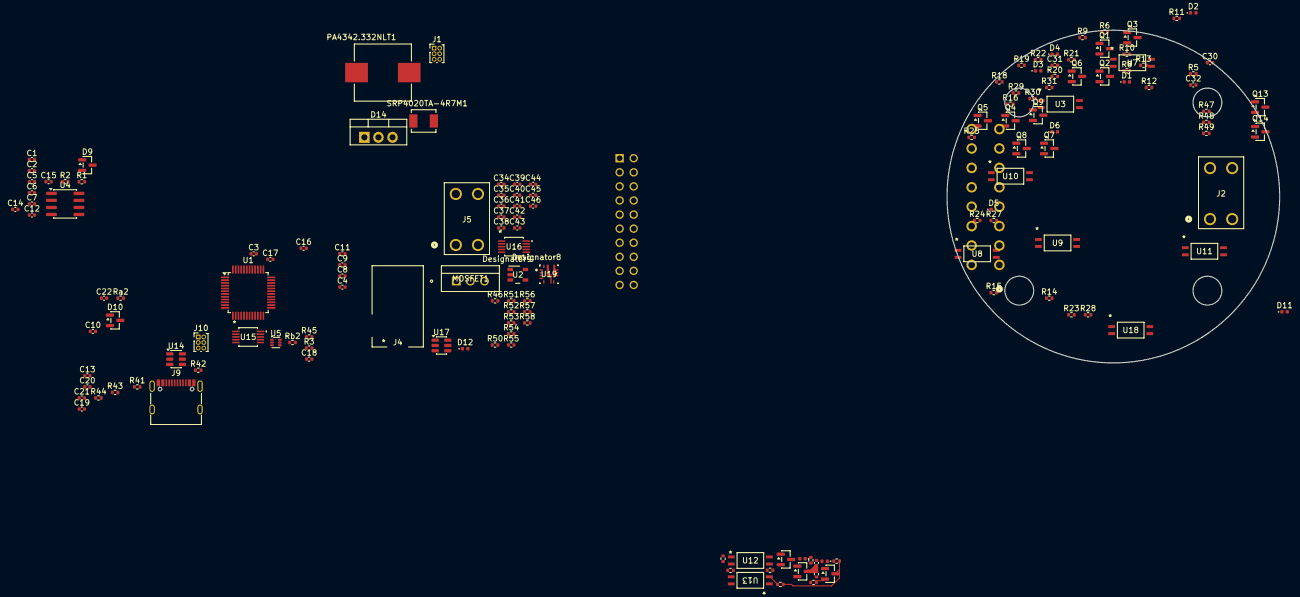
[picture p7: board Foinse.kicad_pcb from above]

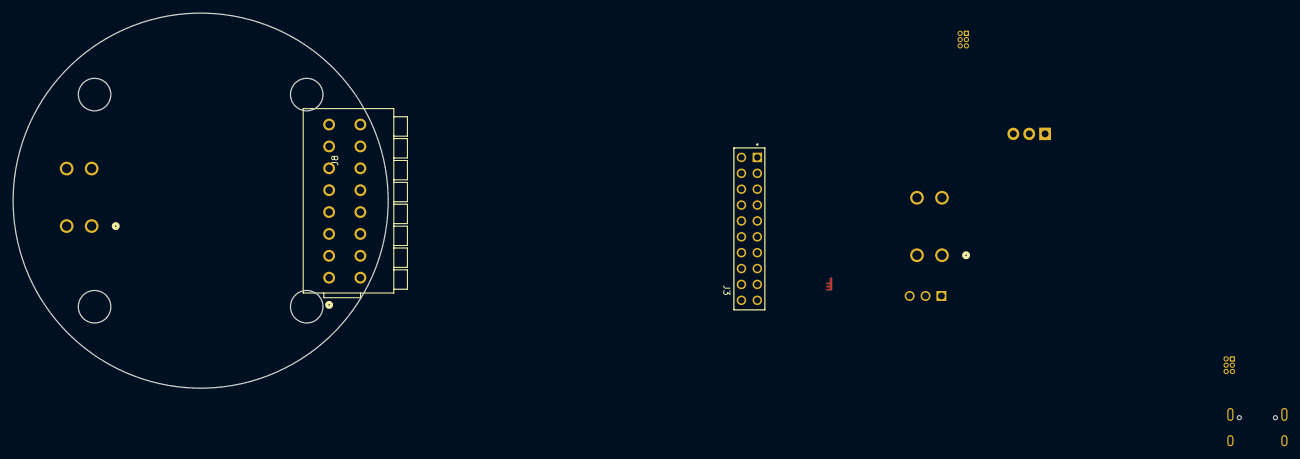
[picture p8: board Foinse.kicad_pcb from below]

Board: 4 copper layers, 60.0 x 60.0 mm, 150 parts (2 on the bottom side), 98 nets.

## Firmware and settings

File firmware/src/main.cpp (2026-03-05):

#if F4
#include "stm32f4xx_hal.h"
#include "platform/stm_f4.h"
#endif
#include "cmsis_os.h"

#include <data.h>
#include <sensor.h>

#include <I2C/I2C_STM.h>
#include <SPI/SPI_STM.h>

#include "tasks/default.h"


void SystemClock_Config(void);
void Error_Handler(void);


int main(void)
{
  HAL_Init();
  SystemClock_Config();
  osKernelInitialize();

  
  static task::Default default_task; 
  default_task.run();

  
  osKernelStart();
  // never get here 
  while (1)
  {
    HAL_Delay(1000);
  }
}



/**
  * @brief System Clock Configuration
  * @retval None
  */
void SystemClock_Config(void)
{
  RCC_OscInitTypeDef RCC_OscInitStruct = {0};
  RCC_ClkInitTypeDef RCC_ClkInitStruct = {0};

  /** Configure the main internal regulator output voltage
  */
  __HAL_RCC_PWR_CLK_ENABLE();
  __HAL_PWR_VOLTAGESCALING_CONFIG(PWR_REGULATOR_VOLTAGE_SCALE1);

  /** Initializes the RCC Oscillators according to the specified parameters
  * in the RCC_OscInitTypeDef structure.
  */
  RCC_OscInitStruct.OscillatorType = RCC_OSCILLATORTYPE_HSI;
  RCC_OscInitStruct.HSIState = RCC_HSI_ON;
  RCC_OscInitStruct.HSICalibrationValue = RCC_HSICALIBRATION_DEFAULT;
  RCC_OscInitStruct.PLL.PLLState = RCC_PLL_ON;
  RCC_OscInitStruct.PLL.PLLSource = RCC_PLLSOURCE_HSI;
  RCC_OscInitStruct.PLL.PLLM = 16;
  RCC_OscInitStruct.PLL.PLLN = 336;
  RCC_OscInitStruct.PLL.PLLP = RCC_PLLP_DIV4;
  RCC_OscInitStruct.PLL.PLLQ = 4;
  if (HAL_RCC_OscConfig(&RCC_OscInitStruct) != HAL_OK)
  {
    Error_Handler();
  }

  /** Initializes the CPU, AHB and APB buses clocks
  */
  RCC_ClkInitStruct.ClockType = RCC_CLOCKTYPE_HCLK|RCC_CLOCKTYPE_SYSCLK
                              |RCC_CLOCKTYPE_PCLK1|RCC_CLOCKTYPE_PCLK2;
  RCC_ClkInitStruct.SYSCLKSource = RCC_SYSCLKSOURCE_PLLCLK;
  RCC_ClkInitStruct.AHBCLKDivider = RCC_SYSCLK_DIV1;
  RCC_ClkInitStruct.APB1CLKDivider = RCC_HCLK_DIV2;
  RCC_ClkInitStruct.APB2CLKDivider = RCC_HCLK_DIV1;

  if (HAL_RCC_ClockConfig(&RCC_ClkInitStruct, FLASH_LATENCY_2) != HAL_OK)
  {
    Error_Handler();
  }
}

void Error_Handler(void)
{
  __disable_irq();
  while (1)
  {
    // stay here
  }
}

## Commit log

2026-01-14 Added E-Match circuit
    [Foinse.kicad_sch]
2026-01-18 Board V1, before review
    [Foinse.kicad_sch]
2026-01-19 Assighned all footprints
    [Foinse.kicad_pcb, Foinse.kicad_sch]
2026-01-20 Fixed shit
    [Foinse.kicad_pcb, Foinse.kicad_sch]
2026-01-20 folders are indded cool
    [Foinse.kicad_pcb, Foinse.kicad_sch]
2026-01-23 minor changes
    [Foinse.kicad_pcb, Foinse.kicad_sch]
2026-01-23 5v logic routed
    [Foinse.kicad_pcb, Foinse.kicad_sch]
2026-01-23 new inductor
    [Foinse.kicad_pcb, Foinse.kicad_sch]
2026-01-23 new inductor2
    [Foinse.kicad_pcb]
2026-01-23 new inductor3
    [Foinse.kicad_pcb]
2026-01-26 can crystal added
    [Foinse.kicad_pcb, Foinse.kicad_sch]
2026-01-30 drc pass
    [Foinse.kicad_pcb, Foinse.kicad_sch]
2026-02-09 lots to do
    [Foinse.kicad_pcb, Foinse.kicad_sch, power.kicad_sch]
2026-02-11 minor stuff
    [Foinse.kicad_pcb, Foinse.kicad_sch, power.kicad_sch]
2026-02-17 added voltage sensing
    [Foinse.kicad_pcb, Foinse.kicad_sch]
2026-02-17 added voltage sensing3
    [Foinse.kicad_pcb]
2026-02-23 ready for review the twost
    [Foinse.kicad_pcb, Foinse.kicad_sch]
2026-02-27 ready to go, nearly
    [Foinse-B_Cu.gbr, Foinse-B_Mask.gbr, Foinse-B_Paste.gbr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]
2026-03-01 ready 2 order
    [Foinse.kicad_pcb]
